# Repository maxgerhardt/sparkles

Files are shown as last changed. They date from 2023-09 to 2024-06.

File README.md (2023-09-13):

# Project sketch: whispering forest fireflies

### Motivation: 
Forests are amazing to illuminate but unfortunately most lighting art i have seen in the past years are immediately recognizable as LED strips. Also i’m looking for a technical challenge.

### Short description: 
build autonomous little waterproof devices that can be hung up in trees. They blink and have a speaker and can triangulate their relative position to each other by using sound. This way we can simply hang them up randomly and know where they are, running light and sound animations through a larger space. 

### How does this work? 
One base station knows its exact location and sends out a timestamp every second or so. During calibration we walk around the forest and produce loud noises, each individual device picks up those noises as peaks and calculates the time difference between the timestamp and the peak, thus collecting a table of runtimes. These runtimes are then sent to the base station and this way we can calculate each position with an accuracy of at least 30cm (which would be 1ms granularity for sound in air) or even quicker. We use ESP-NOW as wifi broadcast for the timestamp and additional commands. 

### How does the hardware look like? 
It’s going to be a custom pcb with a high power led on each side, an esp32, a cheap SMD microphone, a switch and some charging infrastructure, plus a loud speaker  You can plug in a lithium polymer battery and an esp8266 dev board to the pin headers. The whole thing needs to be encased in something waterproof but the idea is to smartly use the ESPs sleep functions to keep the whole thing running for the entire week and only work at night. 

### How do you want to charge 200 devices? 
Actually, we hope to get the battery and power consumption set up in a way that the devices can run for a whole week (power down during daylight etc), but the idea is also to have two notches in the width of a model railway track on the PCBs, so we can stick the boards on a long piece of track and charge all of them more or less at once. We might also do a sound installation during daytime and a light installation at night which creates even bigger need for charging infrastructure

### What challenges are there? 
Many. Getting the math of the audio triangulation right, actually doing some audio triangulation, getting an energy saving way of doing the wifi command stuff, possibly doing our own PWM on the LEDs instead of using WS2812 (e.g. to use brighter LEDs), getting some nice anmations running, also getting the sound animation right, getting all of this done in a cheap fashion etc etc. 

### Costs? 
The cheaper the unit the more we can make. I hope to get a unit including battery for under 10 euros and i hope to get a dream funded that allows us to get 200 units. The cool thing is that every year we could increase the amount of units to make the thing even more sparkly…

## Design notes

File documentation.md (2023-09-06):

# Overall documentation
Here goes everything documentation for the coding process. nothing final, just thoughts

## Messaging flow

- Client boots: 
    - boot client in vicinity of master
    - send address to master
    - wait for master to send timer
    - sync
    - hang up client
    - master continues to send timer
    - if timeout happens, client beeps
- client reboots
    - if calibration message received: delete eeprom and start from scratch
    - else load location data and ID from EEPROM
    - client sends message to master and asks for current time. 

- master upon boot: 
    - send timers including time. 
    - receive addresses
    - if no new address has been received for x minutes or button has been pressed (or upon serial command?): 
        - save all addresses onto EEPROM
        - go into calibration mode
        - announce calibration mode to everyone
    - after calibration mode is done (timeout or  button pressed): 
        - collect times from each address
        - do math
        - save all times onto EEPROM
        - send locations / IDs to clients
    - during animation mode
        - regularly send timers to update

- master upon reboot
    - if active time: 
        - check in with all clients to see if they are still there
    - if sleep mode: 
        - wait until dusk

## differences master - client
- Master has no LED
- Master might have bigger antenna(?)
- master needs clock
- master needs much bigger battery

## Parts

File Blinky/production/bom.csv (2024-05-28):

Designator | Footprint | Quantity | Value | LCSC Part #
C1, C10 | CASE-B_3528 | 2 | 100uf
C11, C9 | 0603 | 2 | 1uF
C12, C3, C8 | 0603 | 3 | 100nF
C13, C14 | 0603 | 2 | 18pf
C2 | 0603 | 1 | 100pF optional
C4 | 0603 | 1 | 470nF
C5 | CAP-SMD_BD8.0-L8.3-W8.3-FD | 1 | 1000uf
C6 | 0603 | 1 | 10uf
C7 | 0603 | 1 | 0.1uF
H1, H2, H3 | MountingHole_3.2mm_M3 | 3 | MountingHole
J1, J2 | HDR-TH_6P-P2.54-V-F | 2 | Conn_01x06_Socket
J3, J5 | JST_PH_B2B-PH-K_1x02_P2.00mm_Vertical | 2 | Battery Connector
J4 | ChargingNotches | 1 | Charging Notches
LED1, LED2 | LED-SMD_XL-HD6070RGBC-A46L | 2 | XL-HD6070RGBC-A46L | C5349977
MIC1 | MIC-TH_BD4.0-P1.4-D0.4-L-FD | 1 | GMI4015P-66DB | C529912
Q1, Q2, Q3, Q4, Q5, Q6 | SOT-23 | 6 | IRLML6244
R1, R11 | 0603 | 2 | 4
R10, R12, R2, R4, R6, R8 | 0603 | 6 | 100
R13, R14, R15, R16, R17, R18, R25, R27, R30, R31, R33 | 0603 | 11 | 100k
R19, R24 | 0603 | 2 | 470k
R20 | 0603 | 1 | 4k7
R21, R22, R23 | 0603 | 3 | 1k
R26 | 0603 | 1 | 47k
R28, R29, R34 | 0603 | 3 | 10k
R3, R5, R7, R9 | 0603 | 4 | 1
R32 | 0603 | 1 | 470R
R35, R36 | 0603 | 2 | 10
SW1 | SW-SMD_MK-12C02-G025 | 1 | MK-12C02-G025 | C778186
T1, T2 | SW-SMD_4P-L5.1-W5.1-P3.70-LS6.5-TL-2 | 2 | TS-1187A-B-A-B | C318884
TXAL1 | Crystal_SMD_3215-2Pin_3.2x1.5mm | 1 | Q13FC1350000400 | C32346
U10 | LED0603-RD_GREEN | 1 | XL-1608SYGC-06 | C965805
U3 | WIRELM-SMD_ESP32-S3-WROOM-1 | 1 | ESP32-S3-WROOM-1-N16R8 | C3040594
U4 | TSSOP-8_L4.4-W3.0-P0.65-LS6.4-BL-2 | 1 | TLV9002IPWR | C398359
U5 | XB4908A | 1 | XB4908A
U6 | ESOP-8_L4.9-W3.9-P1.27-LS6.0-BL-EP | 1 | TP4056_C725790 | C725790
U8 | SOT-23-5_L3.0-W1.7-P0.95-LS2.8-BR | 1 | ME6217C33M5G | C427602
U9 | LED0603-RD_BLUE | 1 | XL-1608UBC-04 | C965807
USB1 | MICRO-USB-SMD_MICROXNJ | 1 | MICROXNJ | C404969

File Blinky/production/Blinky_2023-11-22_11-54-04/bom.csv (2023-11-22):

Designator | Footprint | Quantity | Value | LCSC Part #
C1, C2, C3, C8 | 0603 | 4 | 1uf
C10, C4, C6 | 0603 | 3 | 100uf
C5, C7, C9 | 0603 | 3 | 0.1uF
J1 | PinHeader_1x04_P2.54mm_Vertical | 1 | Conn_01x04_Pin
J2 | PinHeader_1x03_P2.54mm_Vertical | 1 | Conn_01x03_Pin
J3 | JST_PH_B2B-PH-K_1x02_P2.00mm_Vertical | 1 | Battery Connector
J4 | ChargingNotches | 1 | Charging Notches
J5 | CONN-TH_B2B-PH-K-S | 1 | Speaker Connector
Q1, Q2, Q3, Q4, Q5, Q6 | SOT-23 | 6 | IRLML6244
R1, R11, R3, R9 | 0603 | 4 | 1
R10, R12, R19, R2, R4, R6, R8 | 0603 | 7 | 100
R13, R14, R15, R16, R17, R18 | 0603 | 6 | 100k
R20 | 0603 | 1 | 4k7
R21, R22, R23, R25 | 0603 | 4 | 1k
R24 | 0603 | 1 | 3k3
R5, R7 | 0603 | 2 | 2
SW1 | SW-TH_SK12D07VG4 | 1 | SK12D07VG4 | C393937
U1, U2 | LED-SMD_XL-HD6070RGBC-A46L | 2 | XL-HD6070RGBC-A46L | C5349977
U10 | LED0603-RD_GREEN | 1 | XL-1608SYGC-06 | C965805
U3 | WIRELM-SMD_ESP32-S3-WROOM-1 | 1 | ESP32-S2-SOLO-2-N4 | C3040594
U4 | MIC-SMD_3P-L2.8-W1.9_ZTS6056 | 1 | ZTS6156 | C481301
U5 | XB4908A | 1 | XB4908A
U6 | ESOP-8_L4.9-W3.9-P1.27-LS6.0-BL-EP | 1 | TP4056_C725790 | C725790
U7 | MSOP-8_L3.0-W3.0-P0.65-LS5.0-BL | 1 | PAM8304ASR | C56211
U8 | SOT-89-3_L4.5-W2.5-P1.50-LS4.2-BR | 1 | HT7833-A | C14289
U9 | LED0603-RD_BLUE | 1 | XL-1608UBC-04 | C965807

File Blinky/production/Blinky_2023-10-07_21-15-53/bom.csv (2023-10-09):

Designator | Footprint | Quantity | Value | LCSC Part #
C1, C2, C3, C4, C5, C6, C7, C8 | 0603 | 8 | 1uf
J1 | PinHeader_1x03_P2.54mm_Vertical | 1 | Conn_01x03_Pin
J2 | PinHeader_1x04_P2.54mm_Vertical | 1 | Conn_01x04_Pin
J3 | JST_PH_B2B-PH-K_1x02_P2.00mm_Vertical | 1 | Speaker Connector
J4 | PinHeader_1x02_P1.00mm_Horizontal | 1 | Charging Notches
J5 | JST_PH_B2B-PH-K_1x02_P2.00mm_Vertical | 1 | Battery Connector
Q1, Q2, Q3, Q4, Q5, Q6 | SOT-23 | 6 | IRLML6244
R1, R11, R20, R21, R22, R3, R5, R7, R9 | 0603 | 9 | 1
R10, R12, R19, R2, R4, R6, R8 | 0603 | 7 | 100
R13, R14, R15, R16, R17, R18 | 0603 | 6 | 100k
U1, U2 | LED-SMD_XL-HD6070RGBC-A46L | 2 | XL-HD6070RGBC-A46L | C5349977
U10 | SOT-23-6_L2.9-W1.6-P0.95-LS2.8-BR | 1 | DW01_C700964 | C700964
U3 | MIC-SMD_3P-L2.8-W1.9_ZTS6056 | 1 | ZTS6156 | C481301
U4 | WIRELM-SMD_ESP32-S3-WROOM-1 | 1 | ESP32-S2-SOLO-2-N4 | C3040594
U5 | MSOP-8_L3.0-W3.0-P0.65-LS5.0-BL | 1 | PAM8303DBSC | C56211
U6 | ESOP-8_L4.9-W3.9-P1.27-LS6.0-BL-EP | 1 | TP4056_C725790 | C725790
U7 | SW-TH_G-SWITCH_SK-22F02-G060 | 1 | SK-22F02-G060 | C2848869
U8 | LED0603-RD_BLUE | 1 | XL-1608UBC-04 | C965807
U9 | LED0603-RD_GREEN | 1 | XL-1608SYGC-06 | C965805
VR1 | SOT-89-3 | 1 | MCP1700x-330xxMB

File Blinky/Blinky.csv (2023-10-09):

# | Reference | Qty | Value | Footprint | DNP
1 | C1, C2, C3, C4, C5, C6, C7, C8 | 8 | 1uf | Capacitor_SMD:C_0603_1608Metric
2 | J1 | 1 | Conn_01x03_Pin | Connector_PinHeader_2.54mm:PinHeader_1x03_P2.54mm_Vertical
3 | J2 | 1 | Conn_01x04_Pin | Connector_PinHeader_2.54mm:PinHeader_1x04_P2.54mm_Vertical
4 | J3 | 1 | Speaker Connector | Connector_JST:JST_PH_B2B-PH-K_1x02_P2.00mm_Vertical
5 | J4 | 1 | Charging Notches | Connector_PinHeader_1.00mm:PinHeader_1x02_P1.00mm_Horizontal
6 | J5 | 1 | Battery Connector | Connector_JST:JST_PH_B2B-PH-K_1x02_P2.00mm_Vertical
7 | Q1, Q2, Q3, Q4, Q5, Q6 | 6 | IRLML6244 | Package_TO_SOT_SMD:SOT-23
8 | R1, R3, R5, R7, R9, R11, R20, R21, R22 | 9 | 1 | Resistor_SMD:R_0603_1608Metric
9 | R2, R4, R6, R8, R10, R12, R19 | 7 | 100 | Resistor_SMD:R_0603_1608Metric
10 | R13, R14, R15, R16, R17, R18 | 6 | 100k | Resistor_SMD:R_0603_1608Metric
11 | U1, U2 | 2 | XL-HD6070RGBC-A46L | footprint:LED-SMD_XL-HD6070RGBC-A46L
12 | U3 | 1 | ZTS6156 | footprint:MIC-SMD_3P-L2.8-W1.9_ZTS6056
13 | U4 | 1 | ESP32-S2-SOLO-2-N4 | footprint:WIRELM-SMD_ESP32-S3-WROOM-1
14 | U5 | 1 | PAM8303DBSC | footprint:MSOP-8_L3.0-W3.0-P0.65-LS5.0-BL
15 | U6 | 1 | TP4056_C725790 | footprint:ESOP-8_L4.9-W3.9-P1.27-LS6.0-BL-EP
16 | U7 | 1 | XL-1608UBC-04 | footprint:LED0603-RD_BLUE
17 | U8 | 1 | XL-1608SYGC-06 | footprint:LED0603-RD_GREEN
18 | U9 | 1 | DW01_C700964 | footprint:SOT-23-6_L2.9-W1.6-P0.95-LS2.8-BR
19 | U10 | 1 | SK-22F02-G060 | footprint:SW-TH_G-SWITCH_SK-22F02-G060
20 | VR1 | 1 | MCP1700x-330xxMB | Package_TO_SOT_SMD:SOT-89-3

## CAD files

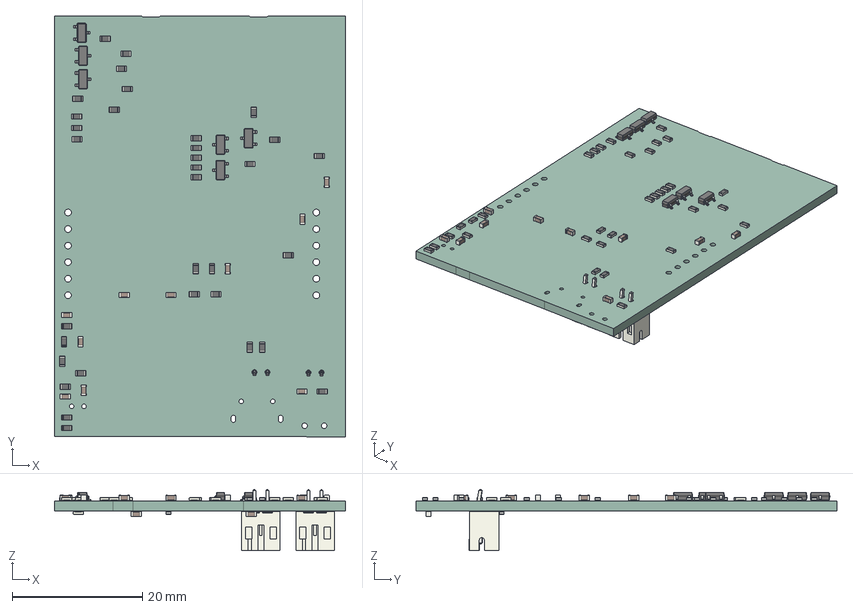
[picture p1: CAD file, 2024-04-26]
Blinky/Blinky.step
44.7 x 64.6 x 9.40 mm
R_0603_1608Metric x 36
SOT_23 x 6
C_0603_1608Metric x 12
JST_B2B_PH_K x 2
_autosave-Blinky_PCB

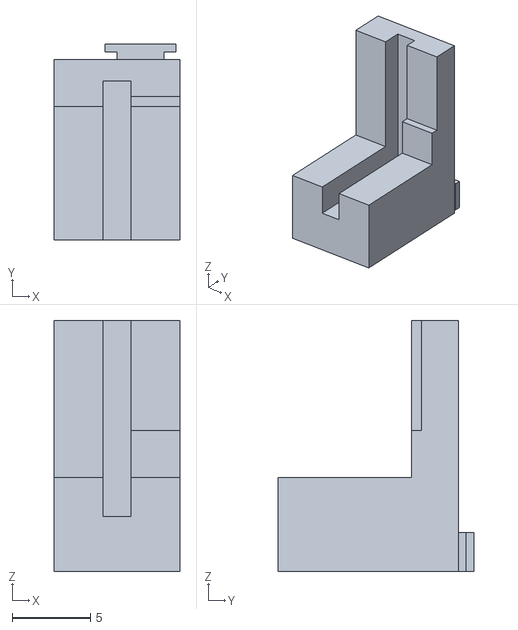
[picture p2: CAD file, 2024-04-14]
carrier_test.stl
8.00 x 12.5 x 16.0

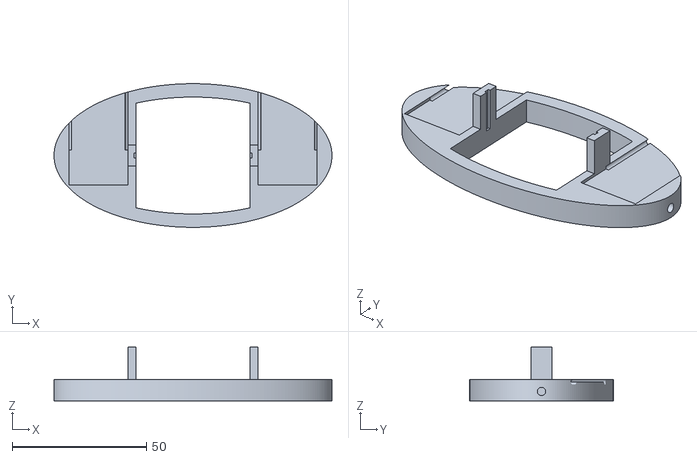
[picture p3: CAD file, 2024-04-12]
Casing/base_v2.stl
103.5 x 53.5 x 20.0

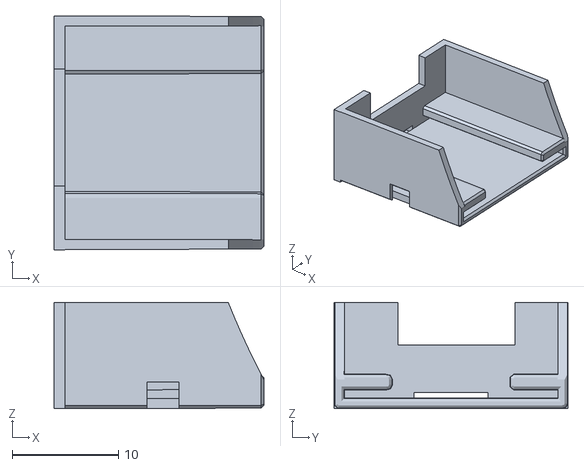
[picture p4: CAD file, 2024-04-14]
battery_casing_test.stl
19.7 x 22.0 x 10.0

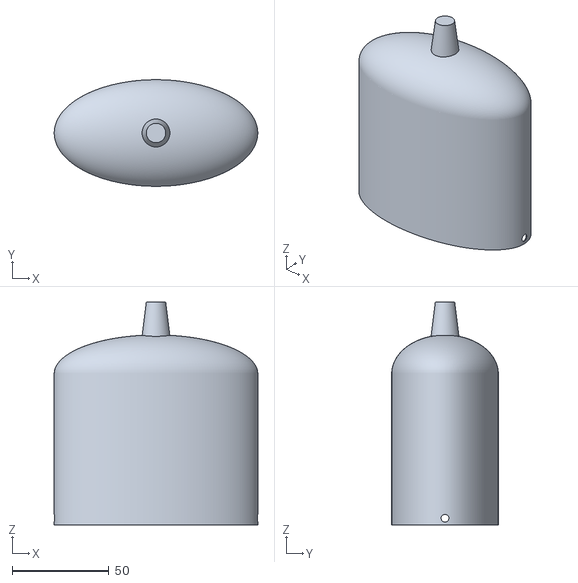
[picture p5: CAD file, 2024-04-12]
Casing/TopV2.stl
105.0 x 55.0 x 115.0

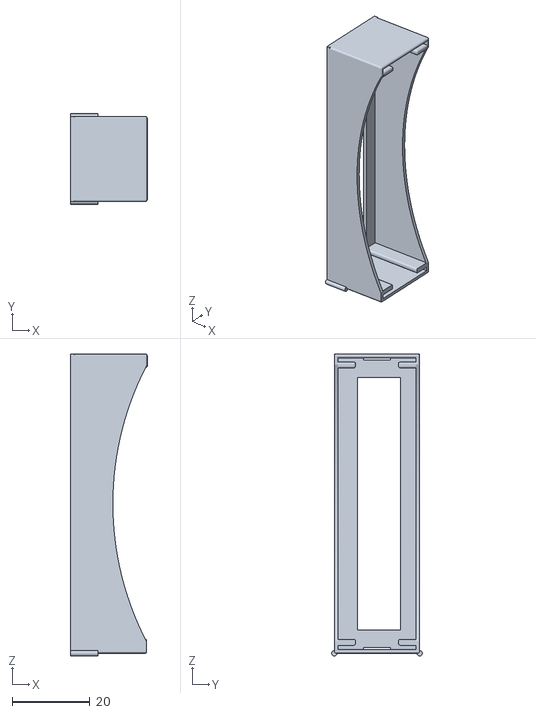
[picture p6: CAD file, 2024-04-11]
Casing/battery_casing.stl
19.7 x 23.4 x 77.9

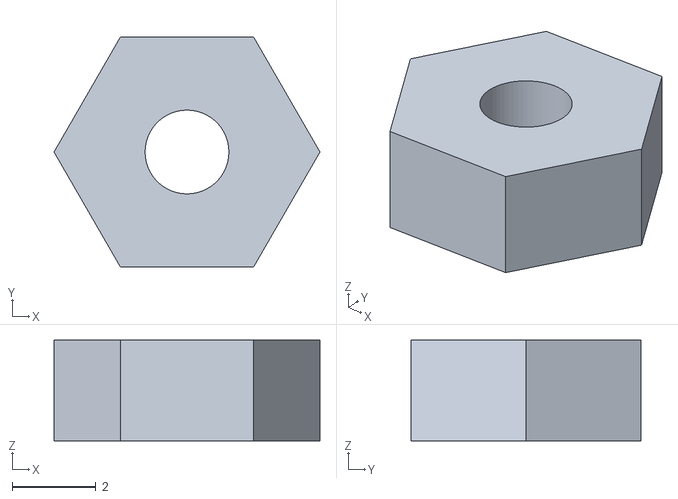
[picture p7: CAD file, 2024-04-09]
nutm3.stl
6.35 x 5.50 x 2.40

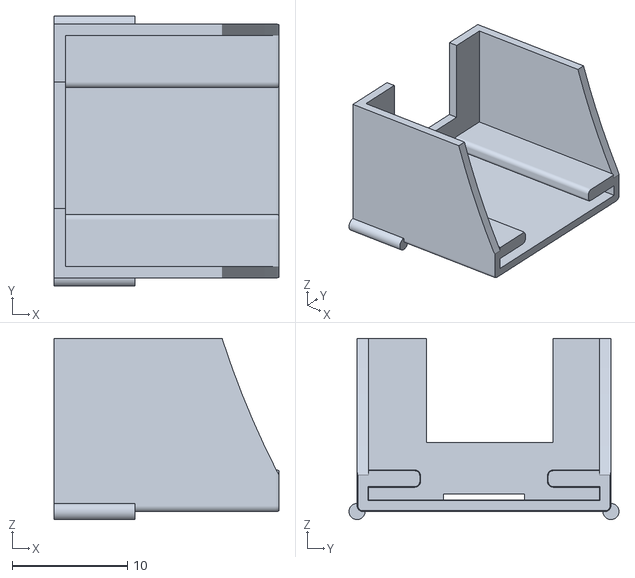
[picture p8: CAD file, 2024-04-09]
half_battery.stl
19.5 x 23.4 x 15.7

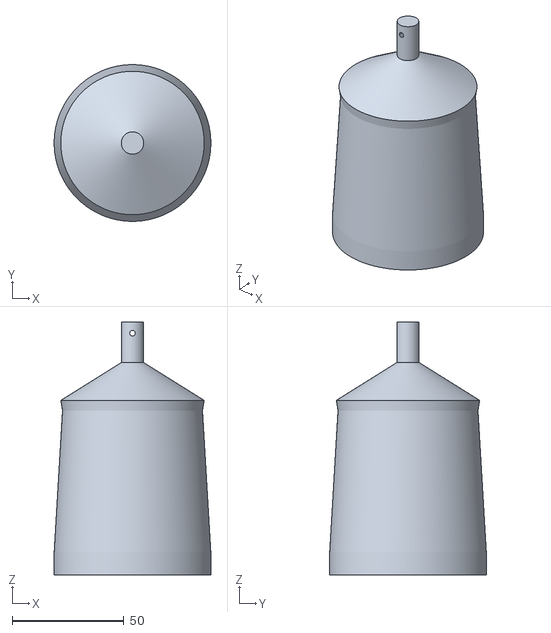
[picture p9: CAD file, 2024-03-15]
Casing/gehaeuse.stl
70.0 x 70.0 x 113.0

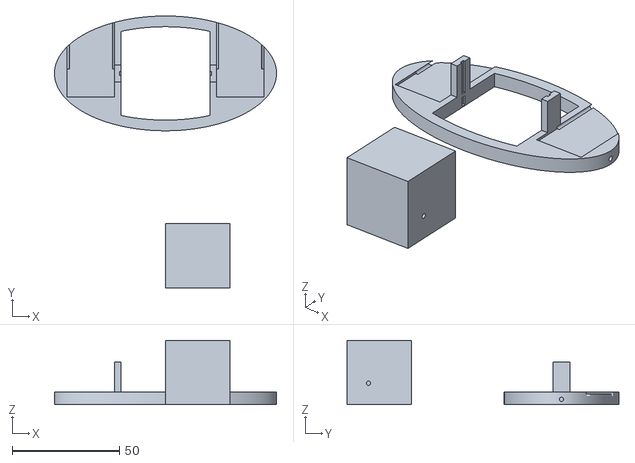
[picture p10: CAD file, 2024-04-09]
newcasing-m3test.stl
103.5 x 126.8 x 30.0

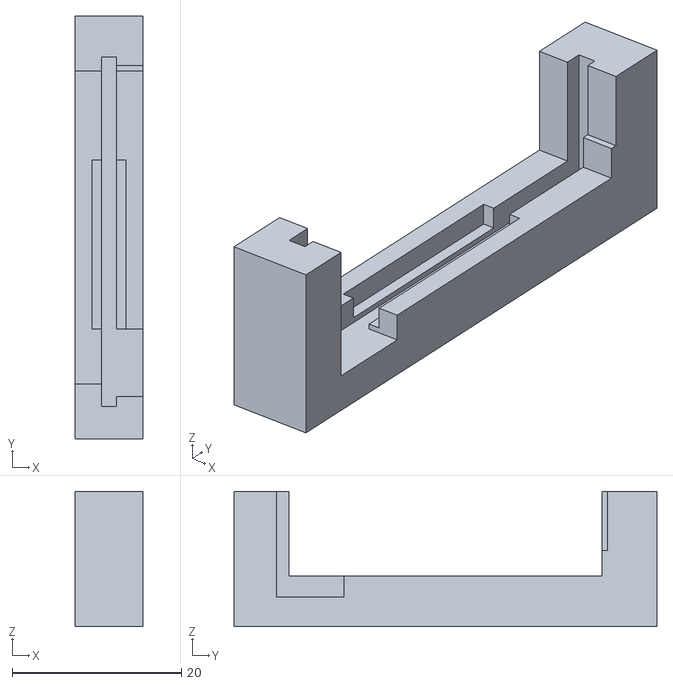
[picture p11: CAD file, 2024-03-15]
Casing/carrier.stl
8.00 x 50.0 x 16.0

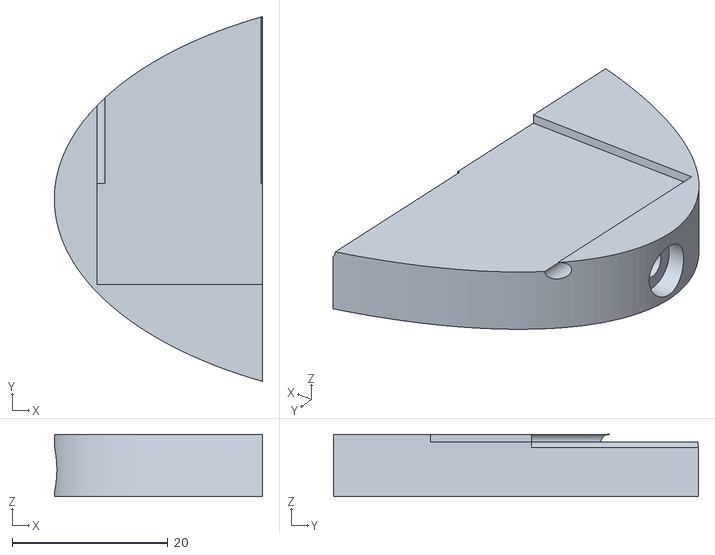
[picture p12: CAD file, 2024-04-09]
half_base.stl
26.8 x 46.8 x 8.00

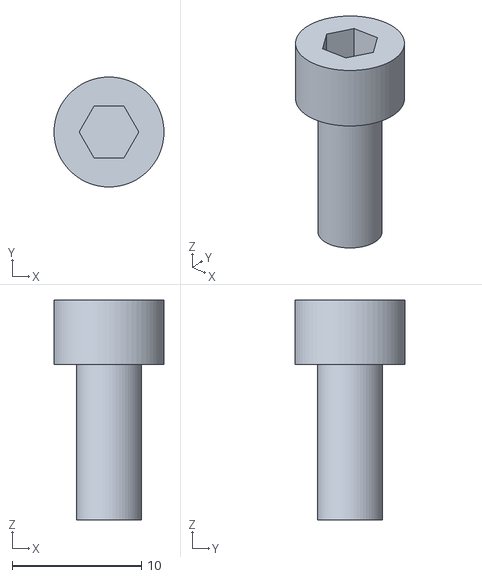
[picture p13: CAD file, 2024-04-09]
screwm5.stl
8.50 x 8.50 x 17.0

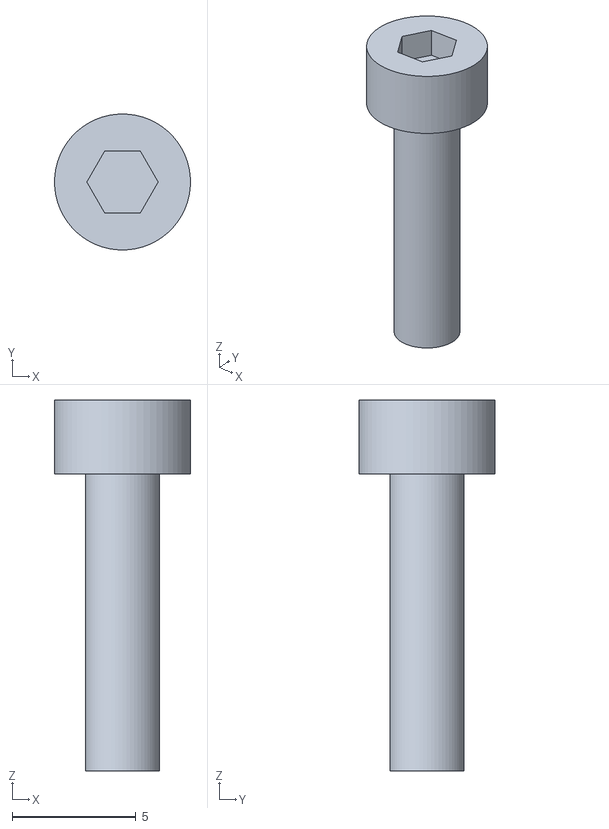
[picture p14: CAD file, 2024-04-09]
screwm3.stl
5.50 x 5.50 x 15.0

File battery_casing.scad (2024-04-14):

include <roundedcube.scad>;
$fa = 1; $fs = $preview ? 2 : 0.5;

$battery_metal_width = 20;
$battery_wall_width = 1;
$battery_outer_width = $battery_metal_width+$battery_wall_width*2;
$battery_metal_thickness = 1.25;
$battery_metal_thickness_2 = 1.25;
$battery_length = 73.55;
$battery_height = 18.75;
$battery_outer_length = 77.2;
$battery_schnupsi_width = 4.5;
$battery_cutout_start = 6;
$battery_cutout_width = $battery_outer_width/2;
$battery_tongue_width = 7;
$battery_casing_height = $battery_height+$battery_wall_width;
module battery_base() { 
    cube([$battery_outer_width, $battery_outer_length, $battery_wall_width]);
}

module battery_wall() {
    //front
    translate([0,0,$battery_wall_width]) roundedcube([$battery_outer_width, $battery_wall_width, $battery_height], false, 0.5, "zmax");
    //back 
    translate([0,$battery_outer_length-$battery_wall_width,$battery_wall_width]) roundedcube([$battery_outer_width, $battery_wall_width, $battery_height], false, 0.5, "zmax");
    //left 
    translate([0,0, $battery_wall_width]) roundedcube([$battery_wall_width, $battery_outer_length, $battery_height], false, 0.5, "zmax");
    //right
    translate([$battery_outer_width-$battery_wall_width,0, $battery_wall_width]) roundedcube([$battery_wall_width, $battery_outer_length, $battery_height], false, 0.5, "zmax");
    //schnupsi
    translate([0, $battery_wall_width+$battery_metal_thickness, $battery_wall_width]) color("blue", 1.0) roundedcube([$battery_wall_width+$battery_schnupsi_width,$battery_wall_width/2, $battery_height], false, 0.5, "zmax");
    //schnupsi
    //translate([$outer_width, $wall_width+$metal_thickness, $wall_width]) color("green", 1.0)  roundedcube([-$wall_width-$schnupsi_width,$wall_width/2, $battery_height], false, 0.5, "zmax");    
    //schnupsi
  translate([$battery_outer_width-$battery_wall_width-$battery_schnupsi_width, $battery_wall_width+$battery_metal_thickness, $battery_wall_width]) color("purple", 1.0) roundedcube([$battery_wall_width+$battery_schnupsi_width,$battery_wall_width/2, $battery_height], false, 0.5, "zmax"); 
    //schnupsi
    //translate([$outer_width, $outer_length-$wall_width-$metal_thickness-$wall_width/2, $wall_width]) color("blue", 1.0)   roundedcube([-$wall_width-$schnupsi_width,$wall_width/2, $battery_height], false, 0.5, "zmax");    
  translate([$battery_outer_width-$battery_wall_width-$battery_schnupsi_width, $battery_outer_length-$battery_wall_width-$battery_metal_thickness_2-$battery_wall_width/2, $battery_wall_width]) color("red", 1.0) roundedcube([$battery_wall_width+$battery_schnupsi_width,$battery_wall_width/2, $battery_height], false, 0.5, "zmax"); 
      translate([0, $battery_outer_length-$battery_wall_width-$battery_metal_thickness_2-$battery_wall_width/2, $battery_wall_width]) color("red", 1.0) roundedcube([$battery_wall_width+$battery_schnupsi_width,$battery_wall_width/2, $battery_height], false, 0.5, "zmax"); 


}

module battery_cutout () {
    translate([6, 6, 0]) cube([$battery_cutout_width, $battery_outer_length-$battery_cutout_start*2, $battery_wall_width]);
     translate([$battery_outer_width/2, $battery_wall_width, 0]) cube([$battery_tongue_width, 1,$battery_wall_width*2], true);
    translate([$battery_outer_width/2, $battery_outer_length-$battery_wall_width, 0]) cube([$battery_tongue_width, 1,$battery_wall_width*2], true);   
    
}
module battery_wall_cutout() {
    translate([0, $battery_outer_length/2, $battery_outer_length+$battery_casing_height/2+$battery_wall_width]) rotate([0,90,0]) cylinder($battery_wall_width, $battery_outer_length, $battery_outer_length);
    translate([$battery_outer_width-$battery_wall_width, $battery_outer_length/2, $battery_outer_length+$battery_casing_height/2+$battery_wall_width]) rotate([0,90,0]) cylinder($battery_wall_width, $battery_outer_length, $battery_outer_length);
}
//battery_wall();
//color("red", 1.0) battery_wall_cutout() ;
module battery_casing() {
    rotate([90, 0, 90]) {
        difference() {
            battery_base();
            battery_cutout();
        }   
        difference () {
            battery_wall();
            battery_wall_cutout();
        }
    }
}
/*
module verbindungsschnupsi() {
    translate([ 0,0.5, 0]) rotate([90,0,0]) cube([3, 2.5, 0.5]); 
    translate([ -0.75,1, 0]) rotate([90,0,0]) cube([4.5, 2.5, 0.5]);   
}
*/
/*
difference() {
    translate([-$battery_casing_height, 0,0]) battery_casing();
    translate([-$battery_outer_width/2, 0, 0]) verbindungsschnupsi() ;
    //translate([-$battery_outer_width, 0, 10]) cube(100, 100, 100);
}
*/
//translate([$battery_outer_width/2,0 , 0]) schnupsi() ;

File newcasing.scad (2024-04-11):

include <battery_casing.scad>;
include <cyl_head_bolt.scad>;
$fa = 1; $fs = $preview ? 2 : 0.5;
$fn = $preview? 20 : 200;

$ellipse_length = 105;
$ellipse_width = 55;
$base_height = 8;
$casing_straight_height = 78;
$casing_roof_height = 20;
$screw_thickness = 2;
$board_width = 43.5;
$board_thickness = 1.75;
$rail_height = 20;
$rail_width = 4.5;
$ellipse_inner_width = $ellipse_width-1.5;
$cutout_square_width = $board_width-1.5;

module elrdcyl(
   w, // width of cylinder
   d, // depth of cylinder
   h1,// straight height of cylinder
   h2 // height of rounded top
   ) {
   intersection(){
     union(){
       scale([w/2,d/2,1])cylinder(r=1,h=h1);  // cylinder
       translate([0,0,h1])scale([w/2,d/2,h2])sphere(r=1);  // top
     }
     scale([w/2,d/2,1])cylinder(r=1,h=h1+h2); // only needed if h2>h1 
   }
}


module cover_main() {
elrdcyl($ellipse_length,$ellipse_width,$casing_straight_height,$casing_roof_height);
}
$notch_height = 20;
$notch_width = 10;
$notch_start = $casing_straight_height+$casing_roof_height-3;
$through_hole = 2.5;
module notch() {
    difference() {
        difference() {
            translate([0, 0, $notch_start])
                cylinder($notch_height, d1=$notch_width+$notch_width/2, d2=$notch_width);
           cover_main();
        }
     translate([0, 0, $notch_start+$notch_height-5]) rotate([90,0,0])  cylinder($notch_width, d1=$through_hole, d2=$through_hole, center=true);
     }
 }

module cover() {

    translate([0, 0, 0]) difference() {
        cover_main();
        translate([0,0,-1]) elrdcyl($ellipse_length-1,$ellipse_width-1,$casing_straight_height, $casing_roof_height-1);
        translate([-$ellipse_length/2, 0, $base_height/2-0.5]) rotate([0,90, 0]) cylinder($ellipse_length, $screw_thickness, $screw_thickness);
    }
    notch();
}

module bottom_base() {
    difference() {
        //base
        translate([0, 100, 0]) elrdcyl($ellipse_length-1.5,$ellipse_inner_width,$base_height, 0);
        //screw
        translate([-$ellipse_length/2, 100, $base_height/2-0.5]) rotate([0,90, 0]) cylinder($ellipse_length, $screw_thickness, $screw_thickness);
        
        
    }
    //rail
    difference() {
        translate([0, 100, 10]) cube([$board_width+$rail_width, 8, $rail_height], true);
        
        //screw
        
        
    }
}

 


module bottom() {

    difference() {
        bottom_base();
        translate([0, 100, $base_height/2]) cube([$cutout_square_width,$board_width+2, $casing_straight_height], true);
    }
    difference() {
         translate([0, 100, 0]) elrdcyl($ellipse_length-1.5,$ellipse_inner_width,$base_height, 0);
        translate([0, 100, 0]) elrdcyl($ellipse_length-10,$ellipse_inner_width-10,$base_height+$rail_height, 0);
    }

}

//cover();

$cutout_insert_width = 3;
$battery_to_rail_distance = 0;
$battery_cutout_width = 2;
$cutout_insert_length = ($ellipse_inner_width/2)-$screw_thickness;
module entire_bottom() {
    difference() {
            bottom();
        //one side cutout
        translate([-($board_width)/2-$rail_width/2-$battery_outer_width, 100-$battery_outer_width/2, $base_height-1]) cube([$battery_outer_width, $ellipse_inner_width, 1]);
          //left
          translate([-$board_width/2-$rail_width/2-$battery_to_rail_distance-$battery_outer_width, 100+($ellipse_inner_width)/2,  $base_height-1]) rotate([90, 270, 0]) cylinder($cutout_insert_length, $battery_cutout_width/2, $battery_cutout_width/2);
          //right
    translate([-$board_width/2-$rail_width/2-$battery_to_rail_distance, 100+($ellipse_inner_width)/2,  $base_height-1]) rotate([90, 270, 0]) cylinder($cutout_insert_length, $battery_cutout_width/2, $battery_cutout_width/2);
        
        //other side cutout
        
          translate([($board_width)/2+$rail_width/2, 100-$battery_outer_width/2, $base_height-1]) cube([$battery_outer_width, $ellipse_inner_width, 1.2]);
          //left
          translate([$board_width/2+$rail_width/2+$battery_to_rail_distance+$battery_outer_width, 100+($ellipse_inner_width)/2,  $base_height-1]) rotate([90, 270, 0]) cylinder($cutout_insert_length, $battery_cutout_width/2, $battery_cutout_width/2);
      
          //right
    translate([$board_width/2+$rail_width/2+$battery_to_rail_distance, 100+($ellipse_inner_width)/2,  $base_height-1]) rotate([90, 270, 0]) cylinder($cutout_insert_length, $battery_cutout_width/2, $battery_cutout_width/2);
      
      //board
      translate([-$board_width/2, 100-$board_thickness/2, $base_height-2]) cube([$board_width, $board_thickness, $rail_height]);
      //screws
          translate([-$ellipse_length/2, 100, $base_height/2-0.5]) rotate([180,90, 0])  hole_through(name="M3", l=12, cld=0.1, h=0, hcld=0.4);
    translate([$ellipse_length/2, 100, $base_height/2-0.5]) rotate([0,90, 0])  hole_through(name="M3", l=12, cld=0.1, h=0, hcld=0.4);
    }
}
    entire_bottom();

//translate([-$cutout_square_width/2-$rail_width-$battery_to_rail_distance-$battery_outer_width-$battery_cutout_width/2, 100+($ellipse_inner_width)/2,  $base_height-1]) rotate([90, 270, 0]) cylinder($cutout_insert_length, $battery_cutout_width/2, $battery_cutout_width/2);




// translate([45/2+$battery_outer_width, 100-$battery_outer_width/2, 10]) rotate([0, 0, 90]) battery_casing();
// translate([-45/2, 100-$battery_outer_width/2, 10]) rotate([0, 0, 90]) battery_casing();


//color("blue", 1.0) translate([-($board_width)/2-$rail_width/2, 100-$battery_outer_width/2+$ellipse_inner_width, $base_height-1]) rotate([0,0,180]) cube([10, $ellipse_inner_width, 1]);

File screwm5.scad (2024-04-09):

include </Users/julian/Code/sparkles/cyl_head_bolt.scad>;
$fn=60;
screw("M3x12");

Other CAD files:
Casing/newcasing.stl
Casing/base.stl
Casing/battery_casing.scad
Casing/battery_viz.scad
Casing/cyl_head_bolt.scad
Casing/data-access.scad
Casing/data-metric_cyl_head_bolts.scad
Casing/gehaeuse.scad
Casing/materials.scad
Casing/newcasing.scad
Casing/roundedcube.scad

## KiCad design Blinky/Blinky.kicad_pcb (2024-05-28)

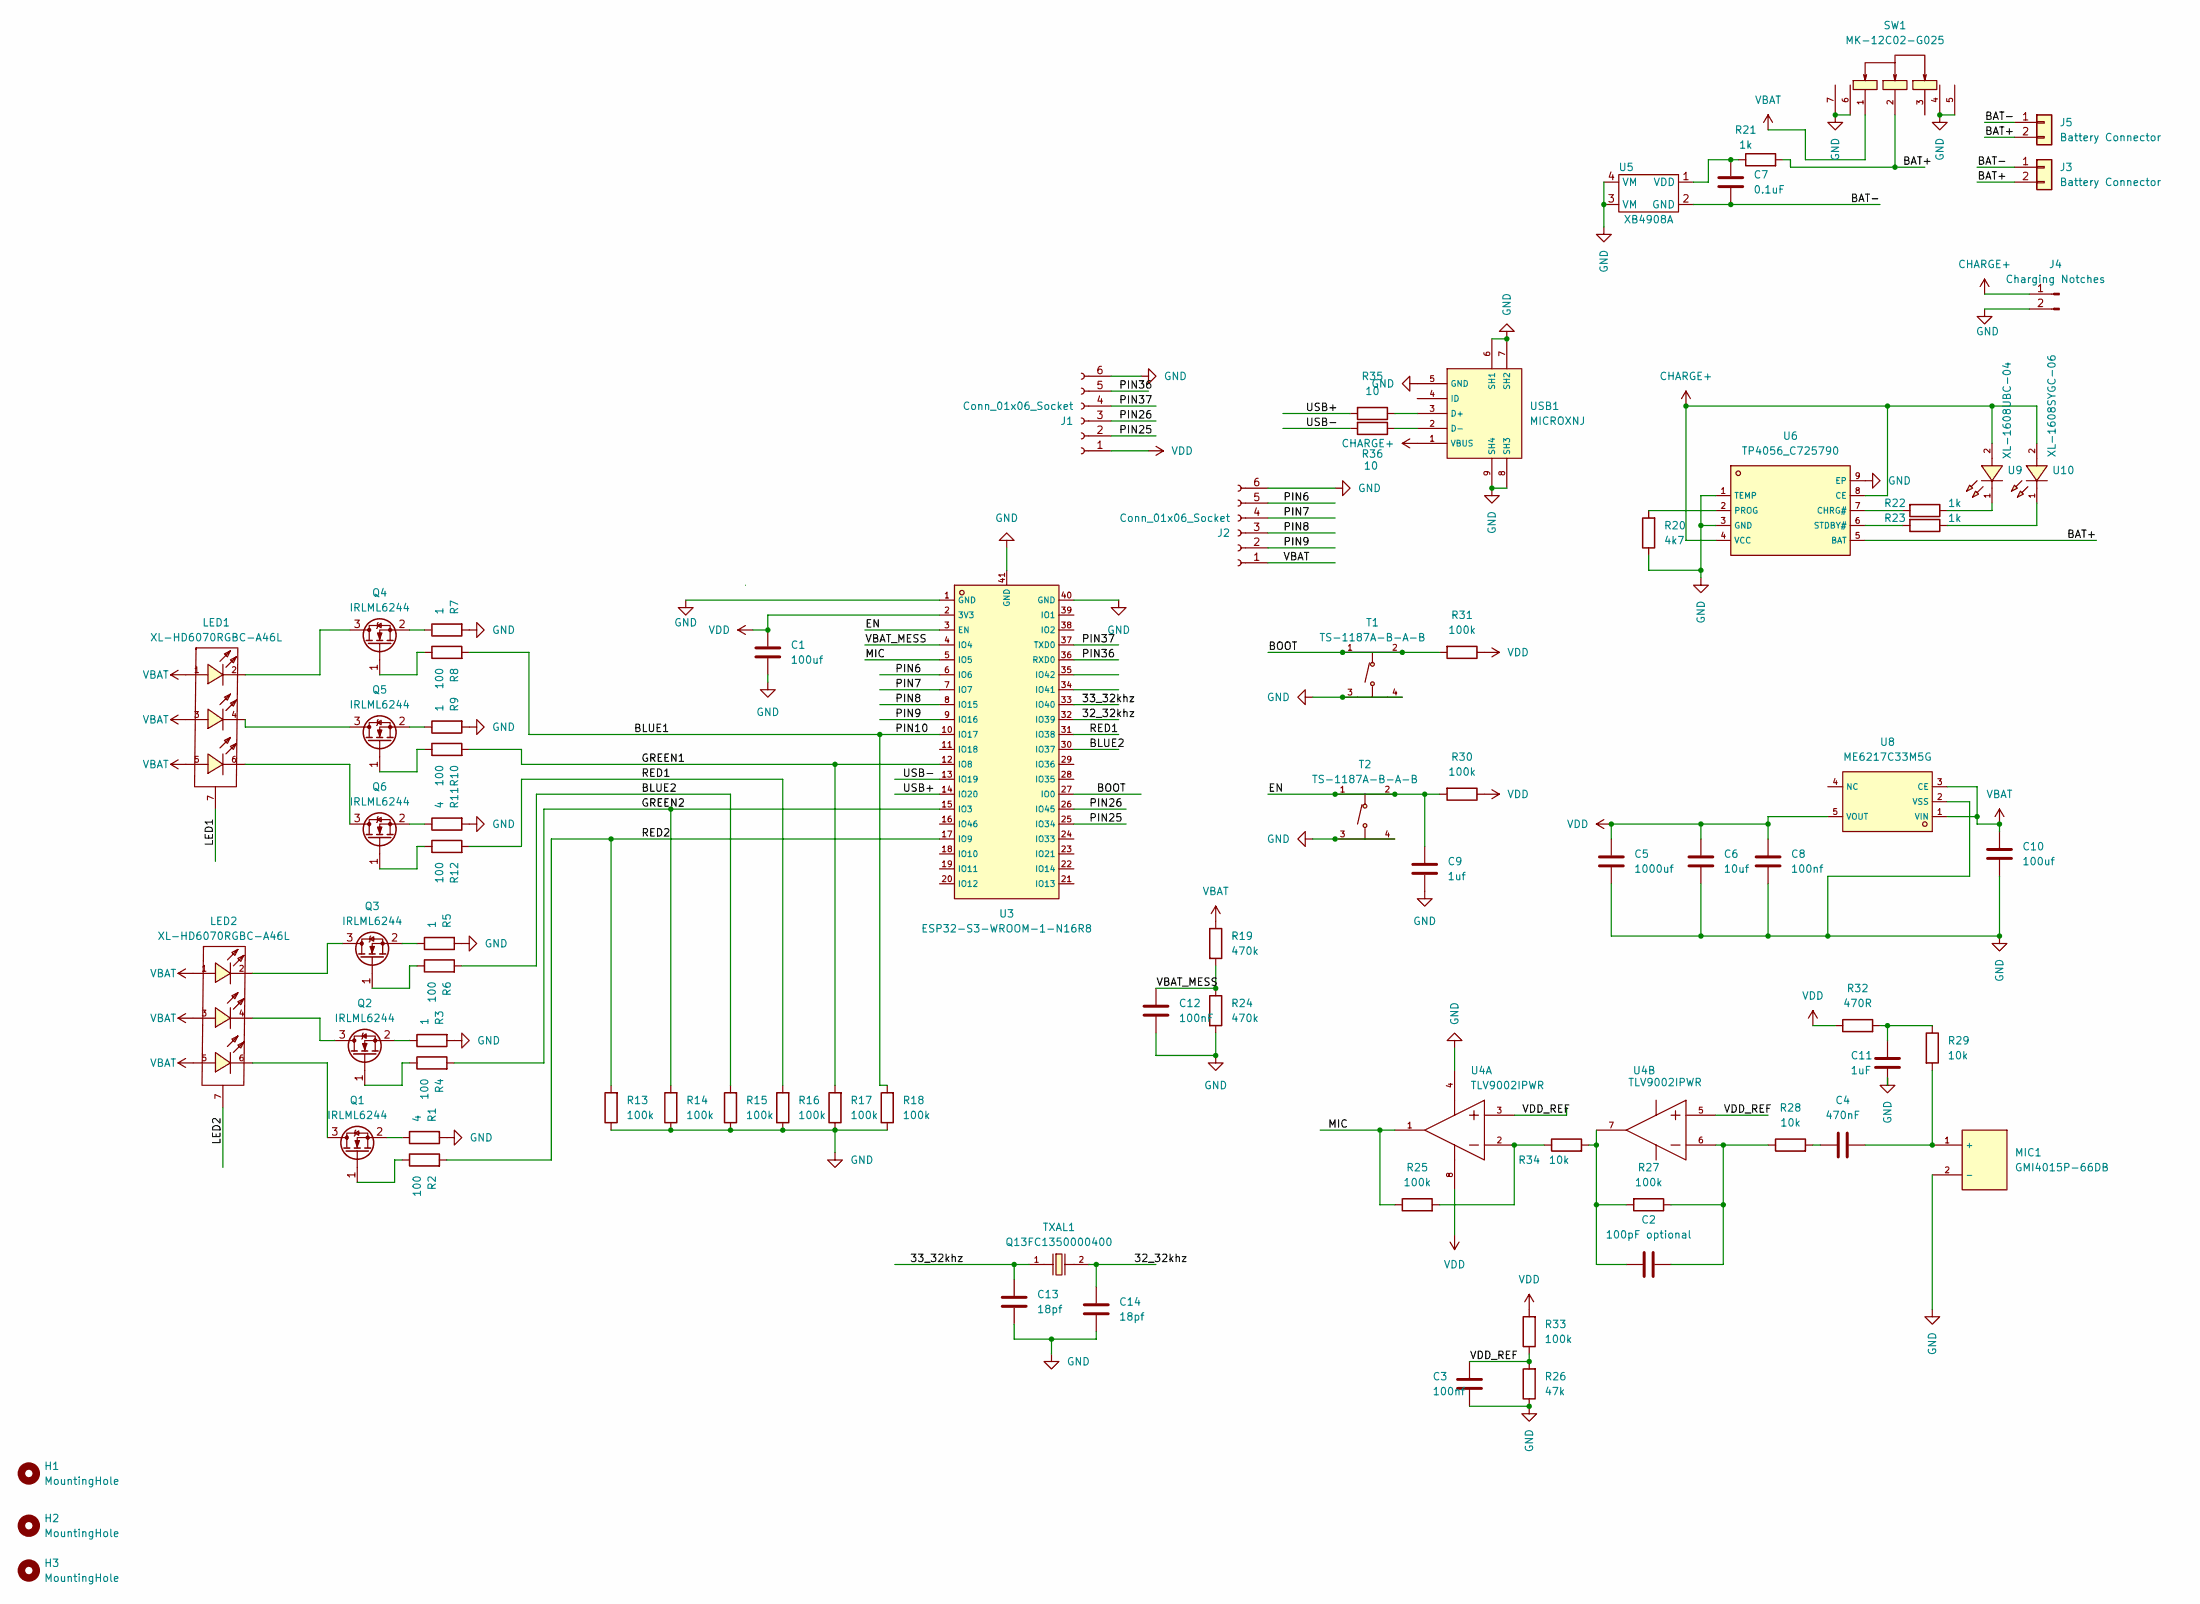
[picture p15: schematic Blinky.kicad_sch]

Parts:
C1, C10: 100uf; CASE-B_3528
C2: 100pF optional; C_0603_1608Metric
C3, C8: 100nf; C_0603_1608Metric
C4: 470nF; C_0603_1608Metric
C5: 1000uf; CAP-SMD_BD8.0-L8.3-W8.3-FD
C6: 10uf; C_0603_1608Metric
C7: 0.1uF; C_0603_1608Metric
C9: 1uf; C_0603_1608Metric
C11: 1uF; C_0603_1608Metric
C12: 100nF; C_0603_1608Metric
C13, C14: 18pf; C_0603_1608Metric
H1, H2, H3: MountingHole; MountingHole_3.2mm_M3
J1, J2: Conn_01x06_Socket; HDR-TH_6P-P2.54-V-F
J3, J5: Battery Connector; JST_PH_B2B-PH-K_1x02_P2.00mm_Vertical
J4: Charging Notches; ChargingNotches
LED1, LED2: XL-HD6070RGBC-A46L; LED-SMD_XL-HD6070RGBC-A46L; LCSC C5349977
MIC1: GMI4015P-66DB; MIC-TH_BD4.0-P1.4-D0.4-L-FD; LCSC C529912
Q1, Q2, Q3, Q4, Q5, Q6: IRLML6244; SOT-23
R1, R11: 4; R_0603_1608Metric
R2, R4, R6, R8, R10, R12: 100; R_0603_1608Metric
R3, R5, R7, R9: 1; R_0603_1608Metric
R13, R14, R15, R16, R17, R18, R25, R27, R30, R31, R33: 100k; R_0603_1608Metric
R19, R24: 470k; R_0603_1608Metric
R20: 4k7; R_0603_1608Metric
R21, R22, R23: 1k; R_0603_1608Metric
R26: 47k; R_0603_1608Metric
R28, R29, R34: 10k; R_0603_1608Metric
R32: 470R; R_0603_1608Metric
R35, R36: 10; R_0603_1608Metric
SW1: MK-12C02-G025; SW-SMD_MK-12C02-G025; LCSC C778186
T1, T2: TS-1187A-B-A-B; SW-SMD_4P-L5.1-W5.1-P3.70-LS6.5-TL-2; LCSC C318884
TXAL1: Q13FC1350000400; Crystal_SMD_3215-2Pin_3.2x1.5mm; LCSC C32346
U3: ESP32-S3-WROOM-1-N16R8; WIRELM-SMD_ESP32-S3-WROOM-1; LCSC C3040594
U4: TLV9002IPWR; TSSOP-8_L4.4-W3.0-P0.65-LS6.4-BL-2; LCSC C398359
U5: XB4908A
U6: TP4056_C725790; ESOP-8_L4.9-W3.9-P1.27-LS6.0-BL-EP; LCSC C725790
U8: ME6217C33M5G; SOT-23-5_L3.0-W1.7-P0.95-LS2.8-BR; LCSC C427602
U9: XL-1608UBC-04; LED0603-RD_BLUE; LCSC C965807
U10: XL-1608SYGC-06; LED0603-RD_GREEN; LCSC C965805
USB1: MICROXNJ; MICRO-USB-SMD_MICROXNJ; LCSC C404969

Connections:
/32_32khz: C14.1, TXAL1.2, U3.32 (IO39)
/33_32khz: C13.1, TXAL1.1, U3.33 (IO40)
/BAT+: J3.2, J5.2, R21.2, SW1.2, U6.5 (BAT)
/BAT-: C7.2, J3.1, J5.1, U5.2 (GND)
/BLUE1: R8.2, R18.2, U3.10 (IO17)
/BLUE2: R6.2, R15.2, U3.30 (IO37)
/BOOT: R31.2, T1.1 (A), T1.2 (B), U3.27 (IO0)
/EN: C9.2, R30.2, T2.1 (A), T2.2 (B), U3.3 (EN)
/GREEN1: R10.2, R17.2, U3.12 (IO8)
/GREEN2: R4.2, R14.2, U3.15 (IO3)
/LED1: LED1.7
/LED2: LED2.7
/MIC: R25.1, U3.5 (IO5), U4.1 (OUT1)
/PIN6: J2.5, U3.6 (IO6)
/PIN7: J2.4, U3.7 (IO7)
/PIN8: J2.3, U3.8 (IO15)
/PIN9: J2.2, U3.9 (IO16)
/PIN25: J1.2, U3.25 (IO34)
/PIN26: J1.3, U3.26 (IO45)
/PIN36: J1.5, U3.36 (RXD0)
/PIN37: J1.4, U3.37 (TXD0)
/RED1: R12.2, R16.2, U3.31 (IO38)
/RED2: R2.2, R13.2, U3.17 (IO9)
/USB+: R35.2, U3.14 (IO20)
/USB-: R36.2, U3.13 (IO19)
/VBAT_MESS: C12.2, R19.2, R24.1, U3.4 (IO4)
/VDD_REF: C3.1, R26.2, R33.1, U4.3 (IN1+), U4.5 (IN2+)
CHARGE+: J4.1, U6.4 (VCC), U6.8 (CE), U9.2 (A), U10.2 (A), USB1.1 (VBUS)
GND: C1.2, C3.2, C5.2, C6.1, C8.1, C9.1, C10.2, C11.2, C12.1, C13.2, C14.2, J1.6, J2.6, J4.2, MIC1.2 (-), R1.2, R3.2, R5.2, R7.2, R9.2, R11.2, R13.1, R14.1, R15.1, R16.1, R17.1, R18.1, R20.1, R24.2, R26.1, SW1.4, SW1.5, SW1.6, SW1.7, T1.3 (C), T1.4 (D), T2.3 (C), T2.4 (D), U3.1 (GND), U3.40 (GND), U3.41 (GND), U4.4 (V-), U5.3 (VM), U5.4 (VM), U6.1 (TEMP), U6.3 (GND), U6.9 (EP), U8.2 (VSS), USB1.5 (GND), USB1.6 (SH1), USB1.7 (SH2), USB1.8 (SH3), USB1.9 (SH4)
unnamed: C4.1, R28.2
unnamed: C11.1, R29.1, R32.2
unnamed: C4.2, MIC1.1 (+), R29.2
unnamed: LED2.6, Q1.3 (D)
unnamed: Q1.1 (G), R2.1
unnamed: Q1.2 (S), R1.1
unnamed: LED2.4, Q2.3 (D)
unnamed: Q2.1 (G), R4.1
unnamed: Q2.2 (S), R3.1
unnamed: LED2.2, Q3.3 (D)
unnamed: Q3.1 (G), R6.1
unnamed: Q3.2 (S), R5.1
unnamed: LED1.2, Q4.3 (D)
unnamed: Q4.1 (G), R8.1
unnamed: Q4.2 (S), R7.1
unnamed: LED1.4, Q5.3 (D)
unnamed: Q5.1 (G), R10.1
unnamed: Q5.2 (S), R9.1
unnamed: LED1.6, Q6.3 (D)
unnamed: Q6.1 (G), R12.1
unnamed: Q6.2 (S), R11.1
unnamed: R25.2, R34.1, U4.2 (IN1-)
unnamed: C2.2, R27.1, R28.1, U4.6 (IN2-)
unnamed: C2.1, R27.2, R34.2, U4.7 (OUT2)
unnamed: C7.1, R21.1, U5.1 (VDD)
unnamed: R22.2, U6.7 (CHRG#)
unnamed: R20.2, U6.2 (PROG)
unnamed: R23.2, U6.6 (STDBY#)
unnamed: R22.1, U9.1 (K)
unnamed: R23.1, U10.1 (K)
unnamed: R35.1, USB1.3 (D+)
unnamed: R36.1, USB1.2 (D-)
VBAT: C10.1, J2.1, LED1.1, LED1.3, LED1.5, LED2.1, LED2.3, LED2.5, R19.1, SW1.1, U8.1 (VIN), U8.3 (CE)
VDD: C1.1, C5.1, C6.2, C8.2, J1.1, R30.1, R31.1, R32.1, R33.2, U3.2 (3V3), U4.8 (V+), U8.5 (VOUT)

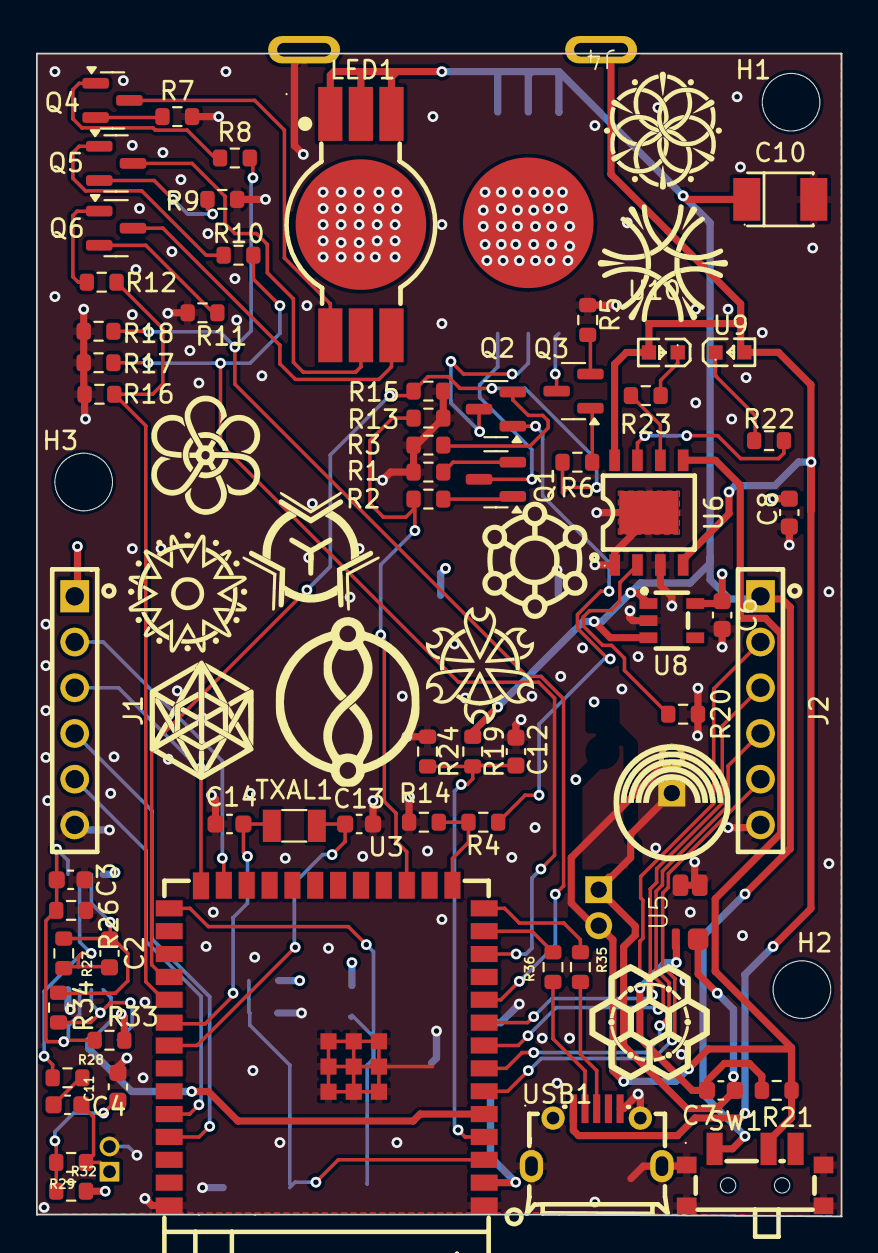
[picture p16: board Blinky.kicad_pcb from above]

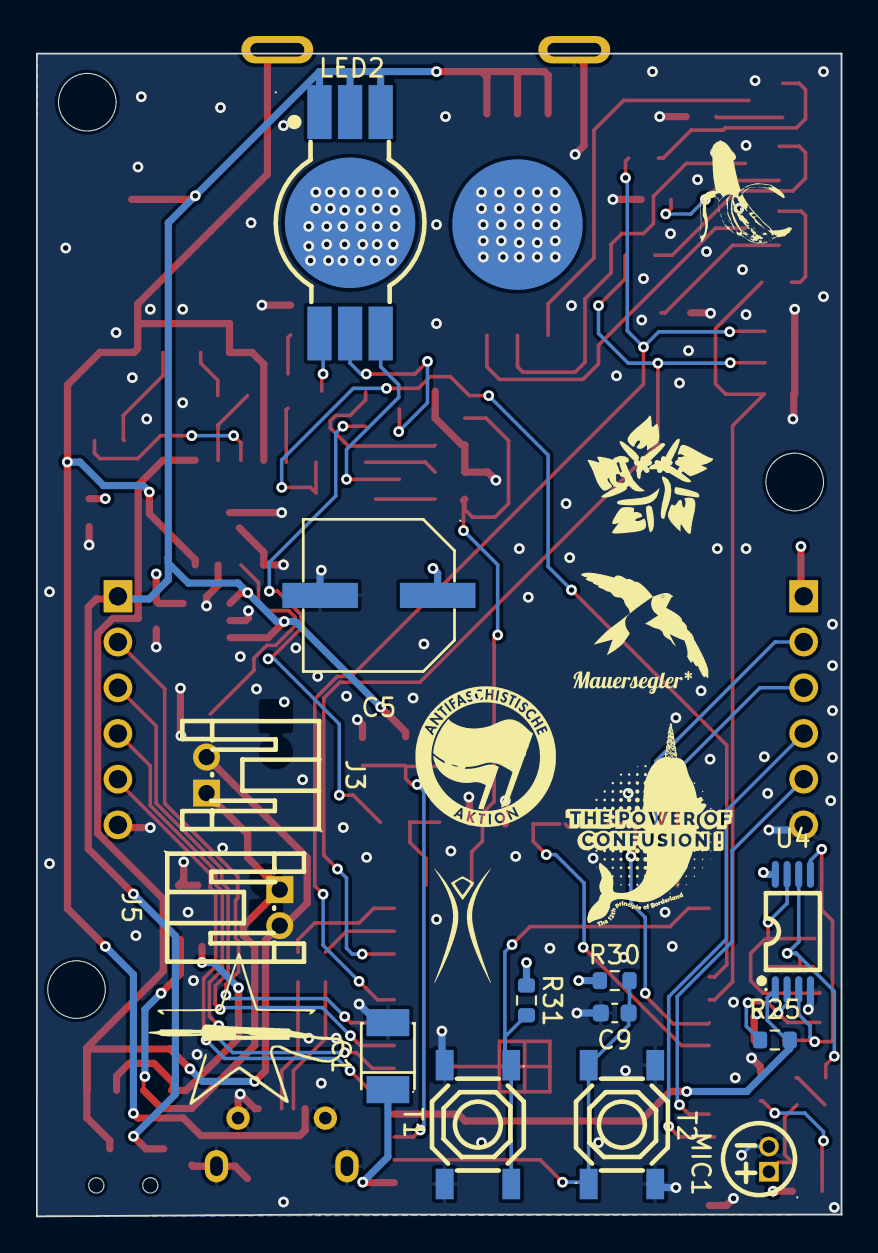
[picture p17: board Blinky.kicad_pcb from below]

Board: 4 copper layers, 44.7 x 64.6 mm, 80 parts (14 on the bottom side), 61 nets.

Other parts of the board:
LOGO102: Logo_Open_Hardware_Large; artwork

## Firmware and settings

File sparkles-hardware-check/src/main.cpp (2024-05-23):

#include <Arduino.h>
#include <esp_now.h>
#include <WiFi.h>
#include <PeakDetection.h> 
//#include <Preferences.h>
#include <LittleFS.h>
int audioPin = 5;
int freq = 5000;
int resolution = 8;

#define LEDC_TIMER_12_BIT  8
#define LEDC_BASE_FREQ     5000
#define LEDC_START_DUTY   (0)
#define LEDC_TARGET_DUTY  (4095)
#define LEDC_FADE_TIME    (3000)

const int ledPinBlue1 = 17;  // 16 corresponds to GPIO16
const int ledPinRed1 = 38; // 17 cmsgrorresponds to GPIO17
const int ledPinGreen1 = 8;  // 5 corresponds to GPIO5
const int ledPinGreen2 = 3;
const int ledPinRed2 = 9;
const int ledPinBlue2 = 37;
const int ledChannelRed1 = 0;
const int ledChannelGreen1 = 1;
const int ledChannelBlue1 = 2;
const int ledChannelRed2 = 3;
const int ledChannelGreen2 = 4;
const int ledChannelBlue2 = 5;

const int batteryPin = 4; 

struct testing {
  bool lighttest = false;
  bool lighttest_full = false;
  bool light_and_send = false;
  bool claptest = true;
  bool measure_battery = false;
  bool deep_sleep_test = false;
  bool read_write_preferences = false;
  bool read_write_struct_littlefs = false;
} testStruct;

uint8_t broadcastAddress[] = {0xFF, 0xFF, 0xFF, 0xFF, 0xFF, 0xFF };
uint8_t myAddress[6];
esp_now_peer_info_t peerInfo;
esp_now_peer_num_t peerNum;
// put function declarations here:
PeakDetection peakDetection; 
//Preferences preferences;
int lastClap;
int claps = 0;
int measurements = 0;
int tick = 0;
unsigned long measurementsTime;
unsigned long measurementsTimeEnd;
unsigned long measurementsTimeRead;
struct message_announce {
  uint8_t messageType = 0;
  unsigned long sendTime;
  int light_level;
  uint8_t address[6];
  int adcVoltage;
  float voltage;
  int counter = 0;
} ;

#define NUM_CLAPS 20

struct message_send_clap_times {
  uint8_t messageType = 1;
  int clapCounter;
  unsigned long timeStamp[NUM_CLAPS]; //offsetted.
};

//4+4*NUM_CLAPS, currently 44
struct client_address {
  uint8_t address[6] = {0x00, 0x00, 0x00, 0x00, 0x00, 0x00};
  int id;
  float xLoc;
  float yLoc;
  float zLoc;
  uint32_t timerOffset;
  int delay;
  message_send_clap_times clapTimes;
  float distance;
};
client_address clientAddress[200];


message_announce announceMessage;

void ledsOff() {
  ledcWrite(ledPinRed2, 0);
  ledcWrite(ledPinGreen2, 0);
  ledcWrite(ledPinBlue2, 0);
  ledcWrite(ledPinRed1, 0);
  ledcWrite(ledPinGreen1, 0);
  ledcWrite(ledPinBlue1, 0);

}

void ledOn(int r, int g, int b, int duration, int frontback) {
  //frontback: 0 front, 1 back, 2 both
  if (frontback == 0 or frontback == 2) {
  ledcWrite(ledPinRed1, r);
  ledcWrite(ledPinGreen1, g);
  ledcWrite(ledPinBlue1, b);
    
  }
  if (frontback == 1 or frontback == 2) {
  ledcWrite(ledPinRed2, r);
  ledcWrite(ledPinGreen2, g);
  ledcWrite(ledPinBlue2, b);
  }

    delay(duration);
}    


void writeStructsToFile(const client_address* data, int count, const char* filename) {
    File file = LittleFS.open(filename, "w");
    if (!file) {
        Serial.println("Failed to open file for writing");
        return;
        
    }
    for (int i = 0; i < count; i++) {
        file.write((uint8_t*)&data[i], sizeof(client_address));
    }
    file.close();
}

// Function to read an array of structs from a file
void readStructsFromFile(client_address* data, int count, const char* filename) {
    File file = LittleFS.open(filename, "r");
    if (!file) {
        Serial.println("Failed to open file for reading");
        return;
    }
    for (int i = 0; i < count; i++) {
        file.read((uint8_t*)&data[i], sizeof(client_address));
    }
    file.close();
    
}

void setup() {
    Serial.begin(115200);
  while (!Serial) {
    ;
  }
  // Set device as a Wi-Fi Station
  WiFi.mode(WIFI_STA);
  if (esp_now_init() != 0) {
    Serial.println("Error initializing ESP-NOW");
    return;
  }
  memcpy(peerInfo.peer_addr, broadcastAddress, 6);
  peerInfo.channel = 0;  
  peerInfo.encrypt = false;

 if (esp_now_add_peer(&peerInfo) != ESP_OK){
    Serial.println("Failed to add peer");
    return;
  }

    if (!LittleFS.begin()) {
        Serial.println("LittleFS Mount Failed");
        if (LittleFS.format()) {
            Serial.println("LittleFS formatted successfully");
        } else {
            Serial.println("LittleFS format failed");
            return;
        }
    }

  analogReadResolution(12);
  analogSetPinAttenuation(batteryPin, ADC_11db);
  WiFi.macAddress(myAddress);
  pinMode(audioPin, INPUT); 
  peakDetection.begin(30, 3, 0);  
  esp_sleep_enable_timer_wakeup(10000000); 
  ledcAttach(ledPinRed1, LEDC_BASE_FREQ, LEDC_TIMER_12_BIT);
  ledcAttach(ledPinGreen1, LEDC_BASE_FREQ, LEDC_TIMER_12_BIT);
  ledcAttach(ledPinBlue1, LEDC_BASE_FREQ, LEDC_TIMER_12_BIT);
  ledcAttach(ledPinRed2, LEDC_BASE_FREQ, LEDC_TIMER_12_BIT);
  ledcAttach(ledPinGreen2, LEDC_BASE_FREQ, LEDC_TIMER_12_BIT);
  ledcAttach(ledPinBlue2, LEDC_BASE_FREQ, LEDC_TIMER_12_BIT);
  ledsOff();
  Serial.println("Setup done ");
  //preferences.begin("sparkles", true);
  // put your setup code here, to run once:
}

void loop() {
while (true) {
  Serial.println("start "+String(tick) );
  delay(100);
  tick++;
  if (tick == 1) {
    tick = 0;
    break;
  }
}


if (testStruct.lighttest == true) {
  Serial.println("Leds individually on");
  Serial.println("Red front");
  ledOn(255, 0, 0, 5000, 0);
  ledsOff();
  Serial.println("Green front");
  ledOn(0, 255, 0, 5000, 0);
  ledsOff();
  Serial.println("Blue front");
  ledOn(0, 0, 255, 5000, 0);
  ledsOff();
  Serial.println("Red back");
  ledOn(255, 0, 0, 5000, 1);
  ledsOff();
  Serial.println("Green back");
  ledOn(0, 255, 0, 5000, 1);
  ledsOff();
  Serial.println("Blue back ");
  ledOn(0, 0, 255, 5000, 1);
  ledsOff();
  Serial.println("Leds together");
  Serial.println("Red both");
  ledOn(255, 0, 0, 5000, 2);
  ledsOff();
  Serial.println("Green both");
  ledOn(0, 255, 0, 5000, 2);
  ledsOff();
  Serial.println("Blue both ");
  ledOn(0, 0, 255, 5000, 2);
  ledsOff();
}
if (testStruct.lighttest_full == true) {
  Serial.println("all");
  ledOn(255, 255, 255, 5000, 2);
  ledsOff();
}
if (testStruct.light_and_send == true) {
  Serial.println("lamps on 64 and sending data");
  announceMessage.light_level = 64;
  announceMessage.counter++;
  ledOn(64, 64, 64, 0, 2);
  esp_now_send(broadcastAddress, (uint8_t *) &announceMessage, sizeof(announceMessage));
  delay(500);
  ledsOff();
  Serial.println("lamps on 128 and sending data");
  announceMessage.light_level = 128;
  announceMessage.counter++;
  ledOn(128, 128, 128, 0, 2);
  esp_now_send(broadcastAddress, (uint8_t *) &announceMessage, sizeof(announceMessage));
  delay(500);
  ledsOff();
  Serial.println("lamps on 192 and sending data");
  announceMessage.light_level = 192;
  announceMessage.counter++;
  ledOn(192, 192, 192, 0, 2);
  delay(500);
  ledsOff();
 esp_now_send(broadcastAddress, (uint8_t *) &announceMessage, sizeof(announceMessage));
/*
  Serial.println("lamps on 255 and sending data");
  announceMessage.light_level = 255;
  ledOn(255, 255, 255, 0, 2);

  esp_now_send(broadcastAddress, (uint8_t *) &announceMessage, sizeof(announceMessage));
  */
  delay(1000);
  ledsOff();
  announceMessage.light_level = 0;

}
if (testStruct.claptest == true) {
  Serial.println("start clapping");

  //Serial.println(sensorValue);
  while (true) {
    double data = (double)analogRead(audioPin)/512-1;
    peakDetection.add(data); 
    int peak = peakDetection.getPeak(); 
    double filtered = peakDetection.getFilt(); 
    if (peak == -1 and millis() > lastClap+1000) {
      lastClap = millis();
      Serial.println("Clap!");
      ledOn(255, 0, 0, 100, true);
      ledsOff();
      claps++;
    }
    if (claps == 3) {
      claps = 0;
      break;
    }
  }
}
if (testStruct.measure_battery == true) {
  while(true) {
    int adcValue = analogRead(batteryPin); // Read the ADC value
    float voltage = adcValue * (3.9 / 4095.0);
    Serial.print("ADC Value: ");
    Serial.print(adcValue);
    Serial.print(" | Voltage: ");
    Serial.print(voltage);
    Serial.println("V");
    announceMessage.adcVoltage = adcValue;
    announceMessage.voltage = voltage;
    announceMessage.counter++;
    esp_now_send(broadcastAddress, (uint8_t *) &announceMessage, sizeof(announceMessage));
    delay(1000);
    measurements++;
    if (measurements == 2) {
      measurements = 0;
      break;
    }
  }
}


if (testStruct.deep_sleep_test == true) {
  Serial.println("Going to sleep now"+String(micros()));
  esp_light_sleep_start();
  Serial.println("Woke up"+String(micros()));
}

if (testStruct.read_write_preferences == true) {
  while (true) {
    Serial.println("Size: "+String(sizeof(clientAddress)));
    testStruct.read_write_preferences = false;
    break;
    }
/*    measurementsTime = micros();
    measurementsTimeRead = preferences.getULong("time");
    measurementsTimeEnd = micros();
    Serial.println("Starting time reading from preferences: "+String(measurementsTime)+" Time to read "+String(measurementsTimeEnd-measurementsTime));
    measurements++;

    if (measurements == 10) {
      measurements = 0;
      break;
    }
  }
  */
}
  if (testStruct.read_write_struct_littlefs == true) {
    /*
     Serial.println("hä");
      while (true) { 
        
        for (int i = 0; i < 200; i++)
        {
        clientAddress[i].address[0] = 0x01;
        clientAddress[i].address[1] = 0x02;
        clientAddress[i].address[2] = 0x03;
        clientAddress[i].address[3] = 0x04;
        clientAddress[i].address[4] = 0x05;
        clientAddress[i].address[5] = 0x06;
        clientAddress[i].id = 1;
        clientAddress[i].xLoc = 1.0;
        clientAddress[i].yLoc = 2.0;
        clientAddress[i].zLoc = 3.0;
        clientAddress[i].timerOffset = 4;
        clientAddress[i].delay = 5;
        clientAddress[i].clapTimes.clapCounter = 6;
        clientAddress[i].clapTimes.timeStamp[0] = 7;
        clientAddress[i].clapTimes.timeStamp[1] = 8;
        clientAddress[i].clapTimes.timeStamp[2] = 9;
        clientAddress[i].clapTimes.timeStamp[3] = 10;
        clientAddress[i].clapTimes.timeStamp[4] = 11;
        clientAddress[i].clapTimes.timeStamp[5] = 12;
        clientAddress[i].clapTimes.timeStamp[6] = 13;
        }

        Serial.println("Size: "+String(sizeof(clientAddress)));
        writeStructsToFile(clientAddress, 200, "/clientAddress");        
        clientAddress[10].id = 8;
        memset(clientAddress, 0, sizeof(clientAddress));
        readStructsFromFile(clientAddress, 200,  "/clientAddress");
            Serial.print("Address: ");
        for (int i = 0; i < 6; i++) {
            Serial.print(clientAddress[10].address[i], HEX);
            if (i < 5) Serial.print(":");
        }
 
        Serial.println();
        Serial.println("ID: "+String(clientAddress[10].id));
        Serial.println("X: "+String(clientAddress[10].xLoc));
        Serial.println("Y: "+String(clientAddress[10].yLoc));
        Serial.println("Z: "+String(clientAddress[10].zLoc));
        Serial.println("TimerOffset: "+String(clientAddress[10].timerOffset));
        Serial.println("Delay: "+String(clientAddress[10].delay));
        Serial.println("ClapCounter: "+String(clientAddress[10].clapTimes.clapCounter));
        testStruct.read_write_struct_littlefs = false; 
       break;
      }
      */
  }
}


  // put your main code here, to run repeatedly:

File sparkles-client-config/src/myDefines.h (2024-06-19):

#include "Arduino.h"
#if DEVICE_USED == 4
#include "espnow.h"
#else 
#include "esp_now.h"
#endif

#include "time.h"
#ifndef DEFINE_H
#define DEFINE_H

//LEDHANDLER
#define LEDC_TIMER_12_BIT  8
#define LEDC_BASE_FREQ     5000
#define LEDC_START_DUTY   (0)
#define LEDC_TARGET_DUTY  (4095)
#define LEDC_FADE_TIME    (3000)

//device modes

#define MAIN 0
#define CLIENT 1
#define WEBSERVER 2

#define GOODNIGHT_HOUR 22 
#define GOODNIGHT_MINUTE 30
#define GOODMORNING_HOUR 4
#define GOODMORNING_MINUTE 30

//flash
#define FLASH_NAMESPACE "sparkles"

//clapping
#define NUM_CLAPS 20
#define CLAP_THRESHOLD 1000000

#define V1 1
#define V2 2
#define V3 3



#if (DEVICE_USED == V1)
    const int ledPinBlue1 = 20;  // 16 corresponds to GPIO16
    const int ledPinRed1 = 9; // 17 corresponds to GPIO17
    const int ledPinGreen1 = 3;  // 5 corresponds to GPIO5
    const int ledPinGreen2 = 8;
    const int ledPinRed2 = 19;
    const int ledPinBlue2 = 18;

#elif (DEVICE_USED == V2)


    const int ledPinBlue1 = 18;  // 16 corresponds to GPIO16
    const int ledPinRed1 = 38; // 17 cmsgrorresponds to GPIO17
    const int ledPinGreen1 = 8;  // 5 corresponds to GPIO5
    const int ledPinGreen2 = 3;
    const int ledPinRed2 = 9;
    const int ledPinBlue2 = 37;
#elif (DEVICE_USED == V3)
    const int ledPinBlue1 = 17;  // 16 corresponds to GPIO16
    const int ledPinRed1 = 38; // 17 cmsgrorresponds to GPIO17
    const int ledPinGreen1 = 8;  // 5 corresponds to GPIO5
    const int ledPinGreen2 = 3;
    const int ledPinRed2 = 9;
    const int ledPinBlue2 = 37;
#endif
//#endif
const int ledChannelRed1 = 0;
const int ledChannelGreen1 = 1;
const int ledChannelBlue1 = 2;
const int ledChannelRed2 = 3;
const int ledChannelGreen2 = 4;
const int ledChannelBlue2 = 5;

//webserv
#define CLAP_PIN 47
#define BATTERY_PIN 4
#define ADDRESS_LIST 1

//MESSAGING
#define MSG_ADDRESS 0
#define MSG_ANNOUNCE 1
#define MSG_TIMER_CALIBRATION 2
#define MSG_GOT_TIMER 3
#define MSG_ASK_CLAP_TIMES 5
#define MSG_SEND_CLAP_TIMES 6
#define MSG_ANIMATION 7
#define MSG_SWITCH_MODE 8
#define MSG_DISTANCE 9
#define MSG_NOCLAPFOUND -1
#define MSG_COMMANDS 101
#define MSG_ADDRESS_LIST 102
#define MSG_STATUS_UPDATE 103
#define MSG_END_CALIBRATION 104
#define MSG_WAKEUP 105
#define MSG_SET_TIME 106
#define MSG_SET_POSITIONS 107
#define MSG_BATTERY_STATUS 108
#define MSG_SET_SLEEP_WAKEUP 109

#define CMD_START 200
#define CMD_MSG_SEND_ADDRESS_LIST 201
#define CMD_START_CALIBRATION_MODE 202
#define CMD_END_CALIBRATION_MODE 203
#define CMD_BLINK 204
#define CMD_MODE_NEUTRAL 205
#define CMD_GET_TIMER 206
#define CMD_START_ANIMATION 207
#define CMD_STOP_ANIMATION 208
#define CMD_DELETE_CLIENTS 209
#define CMD_TIMER_CALIBRATION 210
#define CMD_GO_TO_SLEEP 211
#define CMD_RESET 212
#define CMD_RESET_SYSTEM 213
#define CMD_GET_BATTERY_STATUS 214

#define CMD_END 220


#define NUM_DEVICES 20
#ifndef CALIBRATION_FREQUENCY
#define CALIBRATION_FREQUENCY 1000
#endif
#ifndef TIMER_INTERVAL_MS
#define TIMER_INTERVAL_MS 600
#endif
#define TIMER_ARRAY_COUNT 2


//MESSAGE STRUCTS
struct message_timer {
  uint8_t messageType;
  uint16_t counter;
  unsigned long sendTime;
  uint16_t lastDelay;
  bool reset = false;
  int addressId = 0;
} ;
// 13 bytes

struct message_got_timer {
  uint8_t messageType = MSG_GOT_TIMER;
  uint16_t delayAvg;
  uint32_t timerOffset;
};

struct message_set_sleep_wakeup {
  uint8_t message_type = MSG_SET_SLEEP_WAKEUP;
  unsigned long hours;
  unsigned long minutes;
  unsigned long seconds;
  bool sleep_wakeup;
};

struct message_battery_status {
  uint8_t messageType = MSG_BATTERY_STATUS;
  uint8_t batteryStatus;
};

//9 bytes
struct message_switch_mode {
  uint8_t messageType = MSG_SWITCH_MODE;
  uint8_t mode;
} ;
//2 bytes
struct message_timer_received {
  uint8_t messageType = MSG_GOT_TIMER;
  uint8_t address[6];
  uint32_t timerOffset;
} ;
//14 bytes
struct message_announce {
  uint8_t messageType = MSG_ANNOUNCE;
  unsigned long sendTime;
  uint8_t address[6];
} ;

//15 bytes
struct message_address{
  uint8_t messageType = MSG_ADDRESS;
  uint8_t address[6];
} ;

struct message_distance{
  uint8_t messageType = MSG_DISTANCE;
  float distance;
};

// 7 bytes

struct message_ask_clap_times {
  uint8_t message_type = MSG_ASK_CLAP_TIMES;
  int deviceId;
  int millisA = 0;
  int millisB = 0;
  String debug = "";
};


struct message_send_clap_times {
  uint8_t messageType = MSG_SEND_CLAP_TIMES;
  int clapCounter;
  unsigned long timeStamp[NUM_CLAPS]; //offsetted.
};

struct sleep_wakeup_time {
  int hours;
  int minutes;
  int seconds;
};
//4+4*NUM_CLAPS, currently 44
enum activeStatus {
  ACTIVE, 
  INACTIVE, 
  WAITING, 
  SETTING_TIMER, 
  DEAD,
  UNREACHABLE

};
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

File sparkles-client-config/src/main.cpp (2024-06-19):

#define V1 1
#define V2 2
#define D1 3
#define DEVICE V2

#include "Arduino.h"
#include "esp_now.h"
#include "WiFi.h"
#include "PeakDetection.h"
#include "Preferences.h"


//#include "ESP32TimerInterrupt.h"
#define TIMER_INTERVAL_MS       600
#define USING_TIM_DIV1 true
#include "messaging.h"
#include "ledHandler.h"
#include "stateMachine.h"

#define CALIBRATION_FREQUENCY 1000

int freq = 5000;
int resolution = 8;
bool test = true;
int audioPin = 5;
float redfloat = 0, greenfloat = 0, bluefloat = 0;
uint32_t timerDings;

float rgb[3];

bool gotTimer = false;
PeakDetection peakDetection; 
ledHandler handleLed;
modeMachine modeHandler;
messaging messageHandler;
Preferences preferences;


//Network
//uint8_t broadcastAddress[] = {0xFF, 0xFF, 0xFF, 0xFF, 0xFF, 0xFF};
uint8_t broadcastAddress[] = {0xFF, 0xFF, 0xFF, 0xFF, 0xFF, 0xFF };
uint8_t hostAddress[] = {0x00, 0x00, 0x00, 0x00, 0x00, 0x00 };
uint8_t myAddress[6];
esp_now_peer_info_t peerInfo;
esp_now_peer_num_t peerNum;

//Variables for Time Offset
/*
message_animate animationMessage;
message_clap_time clapTime;
message_address addressMessage;
message_timer timerMessage;
message_got_timer gotTimerMessage;
message_announce announceMessage;
message_mode modeMessage;
message_timer_received timerReceivedMessage;
*/



//timer stuff
uint32_t timeOffset;
uint32_t lastTime = 0;
uint32_t msgSendTime;
uint32_t msgArriveTime;
uint32_t msgReceiveTime;
int timerCounter = 0;
int lastDelay = 0;
int oldTimerCounter = 0;
int timerArray[TIMER_ARRAY_COUNT];
int arrayCounter = 0;
int delayAvg = 0;
//general setup



//calibration stuff
int sensorValue;
int microphonePin = A0;
int lastClap;
int lastFlash;
bool clapSent = false;

//address sending
int addressReceived = false;
int addressSending = 0;


//timer stuff
//ESP32Timer ITimer(0);


int cycleCounter = 0;
/*

void receiveTimer(int messageArriveTime) {
  //add condition that if nothing happened after 5 seconds, situation goes back to start
  //wenn die letzte message maximal 300 mikrosekunden abweicht und der letzte delay auch nicht mehr als 1500ms her war, dann muss die msg korrekt sein
  int difference = messageArriveTime - lastTime ;
  lastDelay = timerMessage.lastDelay;

  if (abs(difference-CALIBRATION_FREQUENCY*TIMER_INTERVAL_MS) < 500 and abs(timerMessage.lastDelay) <2500) {
    if (arrayCounter <TIMER_ARRAY_COUNT) {
      timerArray[arrayCounter] = timerMessage.lastDelay;
    }
    else {
      for (int i = 0; i< TIMER_ARRAY_COUNT; i++) {
        delayAvg += timerArray[i];
      } 
      delayAvg = delayAvg/TIMER_ARRAY_COUNT;
      gotTimerMessage.delayAvg = delayAvg;
      timeOffset = messageArriveTime-timerMessage.sendTime-delayAvg/2;
      //TODO: Make sure the message actually arrives.
      Serial.print("sending GOT_TIMER to ");
      messageHandler.printAddress(hostAddress);

      esp_now_send(hostAddress, (uint8_t *) &gotTimerMessage, sizeof(gotTimerMessage));
      Serial.print("delay avg ");
      Serial.println(delayAvg);
      Serial.println("Should Flash");
      handleLed.flash(255,0,0, 200, 3, 300);
    }
    //damit hab ich den zeitoffset.. 
    // if zeit - timeoffset % 1000 = 0: blink
    //timeOffset = lastTime-oldMessage.sendTime;
    //    Serial.println(esp_now_send(broadcastAddress,(uint8_t *) &timerReceivedMessage, sizeof(timerReceivedMessage) ));
    arrayCounter++;
  }
  else {
    lastTime = messageArriveTime;
  }
}
*/

int testingMode = 0;
int count = 0;
bool didIreset = true;

void OnDataRecv(const esp_now_recv_info * mac, const uint8_t *incomingData, int len) {
    if (incomingData[0] != MSG_ANNOUNCE) {
    messageHandler.addError("RECEIVED MESSAGE "+messageHandler.messageCodeToText(incomingData[0])+" from "+messageHandler.stringAddress(mac->src_addr)+"\n");
    } 
    msgReceiveTime = micros();
    messageHandler.pushDataToReceivedQueue(mac, incomingData, len, msgReceiveTime);
}


void  OnDataSent(const uint8_t *mac_addr, esp_now_send_status_t sendStatus) {
  count++;
  if (messageHandler.getMessagingMode() == MODE_WAIT_ANNOUNCE_RESPONCE) {
    if (sendStatus == ESP_NOW_SEND_SUCCESS) {
      messageHandler.setMessagingMode(MODE_NO_SEND);
      modeHandler.switchMode(MODE_WAIT_FOR_TIMER);
    }
    else {
      messageHandler.setMessagingMode(MODE_RESPOND_ANNOUNCE);
    }
  }
  else if (messageHandler.getMessagingMode() == MODE_WAIT_TIMER_RESPONSE) {
    if (sendStatus == ESP_NOW_SEND_SUCCESS) {
      modeHandler.switchMode(MODE_ANIMATE);
      messageHandler.setMessagingMode(MODE_NO_SEND);
    }
    else {
      messageHandler.setMessagingMode(MODE_RESPOND_TIMER);
    }
  }
  else {
    modeHandler.printCurrentMode();
  }

  //remove peer if conditions are met
}



void setup() {
  // Initialize Serial Monitor
  Serial.begin(115200);
  // Set device as a Wi-Fi Station
  WiFi.mode(WIFI_STA);
  //WiFi.macAddress(addressMessage.address);

  // Init ESP-NOW
  if (esp_now_init() != 0) {
    Serial.println("Error initializing ESP-NOW");
    return;
  }
  memcpy(peerInfo.peer_addr, broadcastAddress, 6);
  peerInfo.channel = 0;  
  peerInfo.encrypt = false;
    // Add peer        
  if (esp_now_add_peer(&peerInfo) != ESP_OK){
    Serial.println("Failed to add peer");
    return;
  }

  handleLed.setup();
  messageHandler.setup(modeHandler, handleLed, peerInfo);
  modeHandler.switchMode(MODE_STARTUP);
  esp_now_register_recv_cb(OnDataRecv);  
  esp_now_register_send_cb(OnDataSent);
   WiFi.macAddress(messageHandler.addressMessage.address);
   esp_now_get_peer_num(&peerNum);
  Serial.print("Number of Peers start: ");
  Serial.println(peerNum.total_num);
   Serial.println("huch");
  pinMode(audioPin, INPUT); 
  peakDetection.begin(30, 3, 0);   
  delay(1000);
  timerDings = micros();
  lastFlash = 0;
  WiFi.macAddress(myAddress);
  messageHandler.announceAddress();
}
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

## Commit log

2023-08-25 Added Calibration Points Generator
2023-08-28 added main config arduino project
2023-08-28 Added client config arduino project
2023-08-30 inbetween / next up rewrite for esp32
2023-09-26 Added Schematic
    [Blinky.csv, Blinky.kicad_pcb, Blinky.kicad_sch]
2023-09-29 beta schematic
    [Blinky.csv, Blinky.kicad_sch]
2023-10-03 updated Schematic
    [Blinky.kicad_sch]
2023-10-10 updated pcb layout
    [Blinky.kicad_pcb, Blinky.kicad_sch, Blinky2.kicad_pcb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]
2023-10-12 updated pcb
    [Blinky2.kicad_pcb, Blinky3.kicad_pcb]
2023-11-22 ordered prototype
    [bom.csv, designators.csv, positions.csv]
2023-12-15 newest version
    [Blinky.kicad_pcb]
2024-02-19 version 1.9
    [Blinky.kicad_pcb]
2024-02-19 version 1.95
    [Blinky.kicad_pcb]
2024-02-19 removed gnd from back of led
    [Blinky.kicad_pcb]
2024-02-19 connected pin headers to GPIOs
    [Blinky.kicad_pcb, Blinky.kicad_sch]
2024-02-19 removed ground connection for LED backside, added flipside led copper
    [Blinky.kicad_pcb, Blinky.kicad_sch]
2024-02-23 switched around resistors for LEDs
    [Blinky.kicad_sch]
2024-02-23 doubled resistor values for LEDs
    [Blinky.kicad_sch]
2024-02-23 added C after voltage reg
    [Blinky.kicad_pcb, Blinky.kicad_sch]
2024-02-25 fixed Vreg and Mic
    [Blinky.kicad_pcb, Blinky.kicad_sch]
2024-02-25 fixed routing of u8 pin 3
    [Blinky.kicad_pcb, Blinky.kicad_sch]
2024-02-27 trying to fix C5
    [Blinky.kicad_pcb, Blinky.kicad_sch]
2024-02-28 reordered and fixed stuff
    [Blinky.kicad_pcb, Blinky.kicad_sch]
2024-02-28 removed some violations
    [Blinky.kicad_pcb]
2024-03-03 review by blueloop
    [Blinky.kicad_pcb, Blinky.kicad_sch]
2024-03-15 3d work and fixed 90 deg rotation in capacitor issue
    [Blinky-B_Cu.gbr, Blinky-B_Mask.gbr, Blinky-B_Paste.gbr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]
2024-03-23 branch commit
    [battery_casing.scad, battery_casing_test.stl, carrier_test.stl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]
2024-03-30 timer works, needs animation
2024-04-09 casing update
    [Blinky.kicad_pcb, Blinky.kicad_sch, base.stl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]
2024-04-09 candle on device 9
2024-04-11 casing almost done
    [base.stl, battery_casing.scad, battery_casing.stl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]
2024-04-11 switching to main
    [battery_casing.scad]
2024-04-11 updated casing
    [base_v2.stl, battery_casing.scad, newcasing.scad]
2024-04-12 bottom cutout width
    [TopV2.stl, base_v2.stl, newcasing.scad]
2024-04-12 fixed casing
    [base_v2.stl, newcasing.scad]
2024-04-14 board v3 0.8
    [Blinky.kicad_pcb, Blinky.kicad_sch]
2024-04-15 updated board
2024-04-18 new Board
    [Blinky.kicad_pcb, Blinky.kicad_sch]
2024-04-28 Delete Blinky/_autosave-Blinky.kicad_pcb
    deleted autosaves
2024-04-28 C1 größerer Footprint Layout angepasst, geprüft Fehlende Footprints ergänzt.
    [Blinky.kicad_pcb, Blinky.kicad_sch]
2024-05-13 can't find this fuckign error
    [ledHandler.cpp, ledHandler.h, main.cpp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]
2024-05-26 fixed final
    [Blinky.kicad_pcb, Blinky.kicad_sch]
2024-05-26 fixed reverse battery connectors
    [Blinky.kicad_pcb, Blinky.kicad_sch]
